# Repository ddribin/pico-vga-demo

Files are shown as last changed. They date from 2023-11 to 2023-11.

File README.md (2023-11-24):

This repository contains the KiCad projects for the "VGA, SD card, and  audio demo boards for Raspberry Pi Pico and Raspberry Pi Pico W" from Chapter 3 of ["Hardware design with RP2040"][hw-design].

- `pico_vga_sd_aud`: Pico version
- `picow_vga_sd_aud`: Pico W version

This is based off of Version 2.2 of the document from 14 June, 2023, but contains some minor updates, such as saving with Version 7, the current version of KiCad.

The original KiCad project for the Pico version can be found at: https://datasheets.raspberrypi.com/rp2040/VGA-KiCAD.zip

The original KiCad project for the Pico W version can be found at: https://datasheets.raspberrypi.com/rp2040/VGA-PicoW-KiCAD.zip

The latest version of "Hardware design with RP2040" can be found at: https://datasheets.raspberrypi.com/rp2040/hardware-design-with-rp2040.pdf

[hw-design]: https://datasheets.raspberrypi.com/rp2040/hardware-design-with-rp2040.pdf

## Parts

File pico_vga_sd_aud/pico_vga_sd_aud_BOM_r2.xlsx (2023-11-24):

RPI-PVAS pico_vga_sd_aud BOM Rev2
17/079/2020
Reference designators | Quantity | Manufacturer Part Number (MPN) | Manufacturer | Description | Value
C1, C2 | 2 | GCM188R71C105KA64J | Murata | CAP CER 1UF 16V X7R 0603 | 1u
C9, C11 | 2 | GRM188R71A225KE15D | Murata | CAP CER 2.2UF 10V X7R 0603 | 2.2u
C3, C10, C16, C19 | 4 | GRM188R61A106KE69J | Murata | CAP CER 10UF 10V X5R 0603 | 10u
C4, C5, C6, C7, C8, C12, C13 | 7 | GRM155R71E104KE14J | Murata | CAP CER 0.1UF 25V X7R 0402 | 100n
C14, C15, C21 | 3 | GRM219R60J476ME44D | Murata | CAP CER 47UF 6.3V X5R 0805 | 47u
C17, C18 | 2 | GRM155R71H222KA01D | Murata | CAP CER 2200PF 50V X7R 0402 | 2.2n
D1 | 1 | MBR120VLSFT1G | ON Semiconductor | DIODE SCHOTTKY 20V 1A SOD123FL | MBR120VLSFT1G
J1, J2 | 2 | SJ-3523-SMT-TR | CUI Devices | CONN JACK STEREO 3.5MM SMD R/A | SJ-3523-SMT
J3 | 1 | 104031-0811 | Molex | CONN MICRO SD CARD PUSH-PULL R/A | 104031-0811
J4 | 1 | L77HDE15SD1CH4F | Amphenol ICC (Commercial Products) | CONN DSUB HD RCPT 15POS R/A SLDR | L77HDE15SD1CH4F
J5 | 1 | 10103594-0001LF | Amphenol ICC (FCI) | CONN RCPT USB2.0 MICRO B SMD R/A | 10103594-0001LF
J6 | 1 | TSW-102-23-T-S | Samtec Inc. | CONN HEADER VERT 2POS 2.54MM | TSW-102-23-T-S
J7 | 1 | 67997-208HLF | Amphenol ICC (FCI) | CONN HEADER VERT 8POS 2.54MM | 67997-208HLF
R1, R2 | 2 | RC0402FR-07220RL | Yageo | RES SMD 220 OHM 1% 1/16W 0402 | 220
R3, R4 | 2 | RC0402FR-07100RL | Yageo | RES SMD 100 OHM 1% 1/16W 0402 | 100
R5, R6 | 2 | RC0402FR-07470RP | Yageo | RES SMD 470 OHM 1% 1/16W 0402 | 470
R7, R8 | 2 | RC0402FR-071K8L | Yageo | RES SMD 1.8K OHM 1% 1/16W 0402 | 1.8K
R10, R11 | 2 | RC0402FR-0747RL | Yageo | RES SMD 47 OHM 1% 1/16W 0402 | 47
R20, R21, R22, R27, R32, R37 | 6 | RC0402FR-071KP | Yageo | RES SMD 1K OHM 1% 1/16W 0402 | 1k
R23, R24 | 2 | RC0402FR-0710KP | Yageo | RES SMD 10K OHM 1% 1/16W 0402 | 10k
R26, R31, R36 | 3 | RC0402FR-07499RL | Yageo | RES SMD 499 OHM 1% 1/16W 0402 | 499
R28, R33, R38 | 3 | RC0402FR-072KL | Yageo | RES SMD 2K OHM 1% 1/16W 0402 | 2k
R29, R34, R39 | 3 | RC0402FR-074K02L | Yageo | RES SMD 4.02K OHM 1% 1/16W 0402 | 4.02k
R30, R35, R40 | 3 | RC0402FR-078K06L | Yageo | RES SMD 8.06K OHM 1% 1/16W 0402 | 8.06k
SW1, SW2, SW3, SW4 | 4 | 434133025816 | Würth Elektronik | TACT SWITCH 4.2X3.2MM VERTICAL T | 434133025816
U1 | 1 | TLV70033DDCR | Texas Instruments | IC REG LINEAR 3.3V 200MA SOT23-5 | TLV70033DDCR
U3 | 1 | NC7WZ16P6X | ON Semiconductor | IC BUF NON-INVERT 5.5V SC70-6 | NC7WZ16P6X
U4 | 1 | PCM5101APWR | Texas Instruments | IC DAC 16/24/32BIT 384K 20TSSOP | PCM5101APWR

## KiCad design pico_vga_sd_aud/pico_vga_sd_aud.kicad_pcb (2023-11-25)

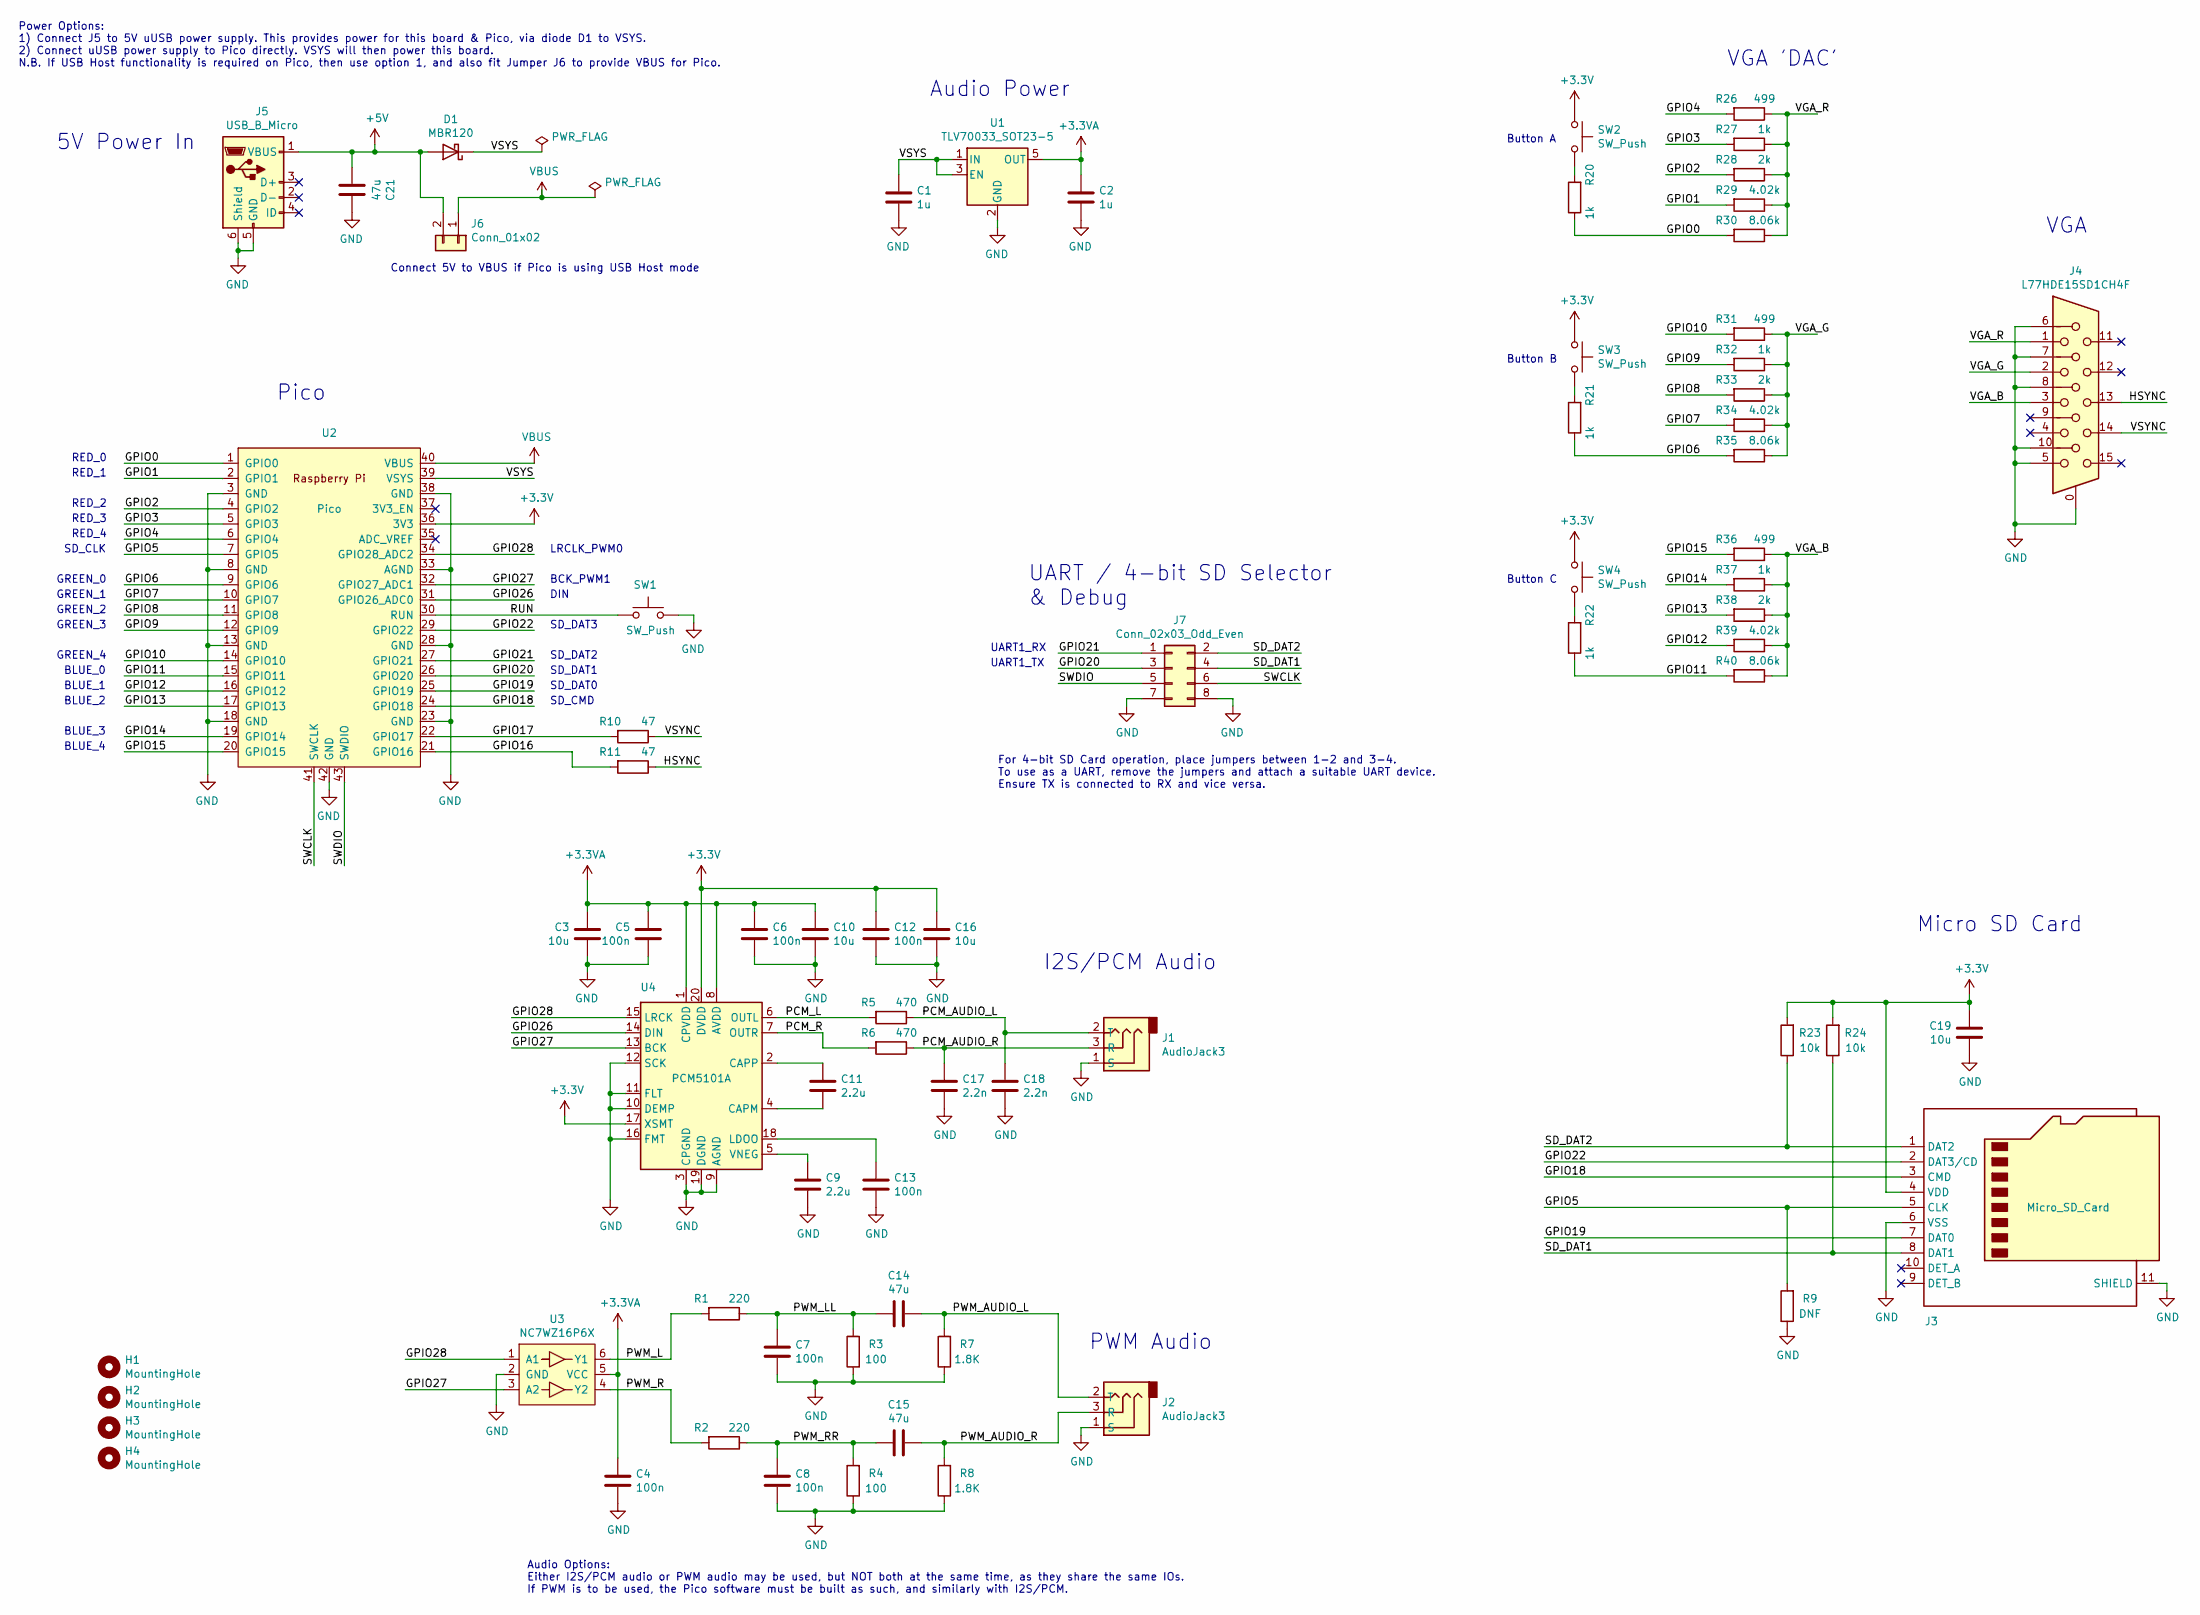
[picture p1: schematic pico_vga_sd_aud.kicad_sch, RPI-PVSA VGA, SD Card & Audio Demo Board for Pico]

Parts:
C1, C2: 1u; C_0603_1608Metric
C3, C10, C16, C19: 10u; C_0603_1608Metric
C4, C5, C6, C7, C8, C12, C13: 100n; C_0402_1005Metric
C9, C11: 2.2u; C_0603_1608Metric
C14, C15, C21: 47u; C_0805_2012Metric
C17, C18: 2.2n; C_0402_1005Metric
D1: MBR120; MBR120_SOD-123
H1, H2, H3, H4: MountingHole; MountingHole_2.7mm_M2.5
J1, J2: AudioJack3; CUI_SJ-3523-audio-jack
J3: Micro_SD_Card; microSD_HC_Molex_104031-0811
J4: L77HDE15SD1CH4F; DSUB-15-L77HDE15SD1CH4F
J5: USB_B_Micro; USB_Micro-B_Amphenol_10103594-0001LF_Horizontal_modified
J6: Conn_01x02; PinHeader_1x02_P2.54mm_Vertical
J7: Conn_02x03_Odd_Even; PinHeader_2x04_P2.54mm_Vertical
R1, R2: 220; R_0402_1005Metric
R3, R4: 100; R_0402_1005Metric
R5, R6: 470; R_0402_1005Metric
R7, R8: 1.8K; R_0402_1005Metric
R9: DNF; R_0402_1005Metric
R10, R11: 47; R_0402_1005Metric
R20, R21, R22, R27, R32, R37: 1k; R_0402_1005Metric
R23, R24: 10k; R_0402_1005Metric
R26, R31, R36: 499; R_0402_1005Metric
R28, R33, R38: 2k; R_0402_1005Metric
R29, R34, R39: 4.02k; R_0402_1005Metric
R30, R35, R40: 8.06k; R_0402_1005Metric
SW1, SW2, SW3, SW4: SW_Push; SW_Push_1P1T_NO_Vertical_Wuerth_434133025816
U1: TLV70033_SOT23-5; SOT-23-5
U2: Pico; RPi_Pico_SMD
U3: NC7WZ16P6X; SOT-363_SC-70-6
U4: PCM5101A; TSSOP-20_4.4x6.5mm_P0.65mm

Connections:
+3.3V: C12.1, C16.1, C19.1, J3.4 (VDD), R23.2, R24.2, SW2.1, SW3.1, SW4.1, U2.36 (3V3), U4.17 (XSMT), U4.20 (DVDD)
+3.3VA: C2.1, C3.1, C4.1, C5.1, C6.1, C10.1, U1.5 (OUT), U3.5 (VCC), U4.1 (CPVDD), U4.8 (AVDD)
+5V: C21.2, D1.2 (A), J5.1 (VBUS), J6.2
/GPIO0: R20.1, R30.2, U2.1 (GPIO0)
/GPIO1: R29.2, U2.2 (GPIO1)
/GPIO2: R28.2, U2.4 (GPIO2)
/GPIO3: R27.2, U2.5 (GPIO3)
/GPIO4: R26.2, U2.6 (GPIO4)
/GPIO5: J3.5 (CLK), R9.2, U2.7 (GPIO5)
/GPIO6: R21.1, R35.2, U2.9 (GPIO6)
/GPIO7: R34.2, U2.10 (GPIO7)
/GPIO8: R33.2, U2.11 (GPIO8)
/GPIO9: R32.2, U2.12 (GPIO9)
/GPIO10: R31.2, U2.14 (GPIO10)
/GPIO11: R22.1, R40.2, U2.15 (GPIO11)
/GPIO12: R39.2, U2.16 (GPIO12)
/GPIO13: R38.2, U2.17 (GPIO13)
/GPIO14: R37.2, U2.19 (GPIO14)
/GPIO15: R36.2, U2.20 (GPIO15)
/GPIO16: R11.2, U2.21 (GPIO16)
/GPIO17: R10.2, U2.22 (GPIO17)
/GPIO18: J3.3 (CMD), U2.24 (GPIO18)
/GPIO19: J3.7 (DAT0), U2.25 (GPIO19)
/GPIO20: J7.3, U2.26 (GPIO20)
/GPIO21: J7.1, U2.27 (GPIO21)
/GPIO22: J3.2 (DAT3/CD), U2.29 (GPIO22)
/GPIO26: U2.31 (GPIO26_ADC0), U4.14 (DIN)
/GPIO27: U2.32 (GPIO27_ADC1), U3.3 (A2), U4.13 (BCK)
/GPIO28: U2.34 (GPIO28_ADC2), U3.1 (A1), U4.15 (LRCK)
/HSYNC: J4.13, R11.1
/PCM_AUDIO_L: C18.1, J1.2 (T), R5.1
/PCM_AUDIO_R: C17.1, J1.3 (R), R6.1
/PCM_L: R5.2, U4.6 (OUTL)
/PCM_R: R6.2, U4.7 (OUTR)
/PWM_AUDIO_L: C14.1, J2.2 (T), R7.2
/PWM_AUDIO_R: C15.1, J2.3 (R), R8.2
/PWM_L: R1.2, U3.6 (Y1)
/PWM_LL: C7.1, C14.2, R1.1, R3.2
/PWM_R: R2.2, U3.4 (Y2)
/PWM_RR: C8.1, C15.2, R2.1, R4.2
/RUN: SW1.1, U2.30 (RUN)
/SD_DAT1: J3.8 (DAT1), J7.4, R24.1
/SD_DAT2: J3.1 (DAT2), J7.2, R23.1
/SWCLK: J7.6, U2.41 (SWCLK)
/SWDIO: J7.5, U2.43 (SWDIO)
/VGA_B: J4.3, R36.1, R37.1, R38.1, R39.1, R40.1
/VGA_G: J4.2, R31.1, R32.1, R33.1, R34.1, R35.1
/VGA_R: J4.1, R26.1, R27.1, R28.1, R29.1, R30.1
/VSYNC: J4.14, R10.1
/VSYS: C1.1, D1.1 (K), U1.1 (IN), U1.3 (EN), U2.39 (VSYS)
GND: C1.2, C2.2, C3.2, C4.2, C5.2, C6.2, C7.2, C8.2, C9.2, C10.2, C12.2, C13.2, C16.2, C17.2, C18.2, C19.2, C21.1, J1.1 (S), J2.1 (S), J3.6 (VSS), J3.11 (SHIELD), J4.0, J4.5, J4.6, J4.7, J4.8, J4.10, J5.5 (GND), J5.6 (Shield), J7.7, J7.8, R3.1, R4.1, R7.1, R8.1, R9.1, SW1.2, U1.2 (GND), U2.3 (GND), U2.8 (GND), U2.13 (GND), U2.18 (GND), U2.23 (GND), U2.28 (GND), U2.33 (AGND), U2.38 (GND), U2.42 (GND), U3.2 (GND), U4.3 (CPGND), U4.9 (AGND), U4.10 (DEMP), U4.11 (FLT), U4.12 (SCK), U4.16 (FMT), U4.19 (DGND)
unnamed: R20.2, SW2.2
unnamed: R21.2, SW3.2
unnamed: R22.2, SW4.2
unnamed: C11.2, U4.4 (CAPM)
unnamed: C11.1, U4.2 (CAPP)
unnamed: C13.1, U4.18 (LDOO)
unnamed: C9.1, U4.5 (VNEG)
VBUS: J6.1, U2.40 (VBUS)

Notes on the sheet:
RED_4
RED_0
GREEN_0
SD_CLK
PWM Audio
SD_CMD
SD_DAT3
RED_3
UART1_RX
LRCLK_PWM0
DIN
BLUE_1
VGA
BCK_PWM1
SD_DAT1
GREEN_3
GREEN_2
UART / 4-bit SD Selector & Debug
RED_2
GREEN_4
Audio Options: Either I2S/PCM audio or PWM audio may be used, but NOT both at the same time, as they share the same IOs. If PWM is to be used, the Pico software must be built as such, and similarly with I2S/PCM.
I2S/PCM Audio
Audio Power
Button C
5V Power In
VGA 'DAC'
Button A
SD_DAT0
Power Options: 1) Connect J5 to 5V uUSB power supply. This provides power for this board & Pico, via diode D1 to VSYS. 2) Connect uUSB power supply to Pico directly. VSYS will then power this board. N.B. If USB Host functionality is required on Pico, then use option 1, and also fit Jumper J6 to pro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
Connect 5V to VBUS if Pico is using USB Host mode
Button B
Pico
For 4-bit SD Card operation, place jumpers between 1-2 and 3-4. To use as a UART, remove the jumpers and attach a suitable UART device. Ensure TX is connected to RX and vice versa.
BLUE_4
RED_1
BLUE_3
BLUE_0
UART1_TX
Micro SD Card
GREEN_1

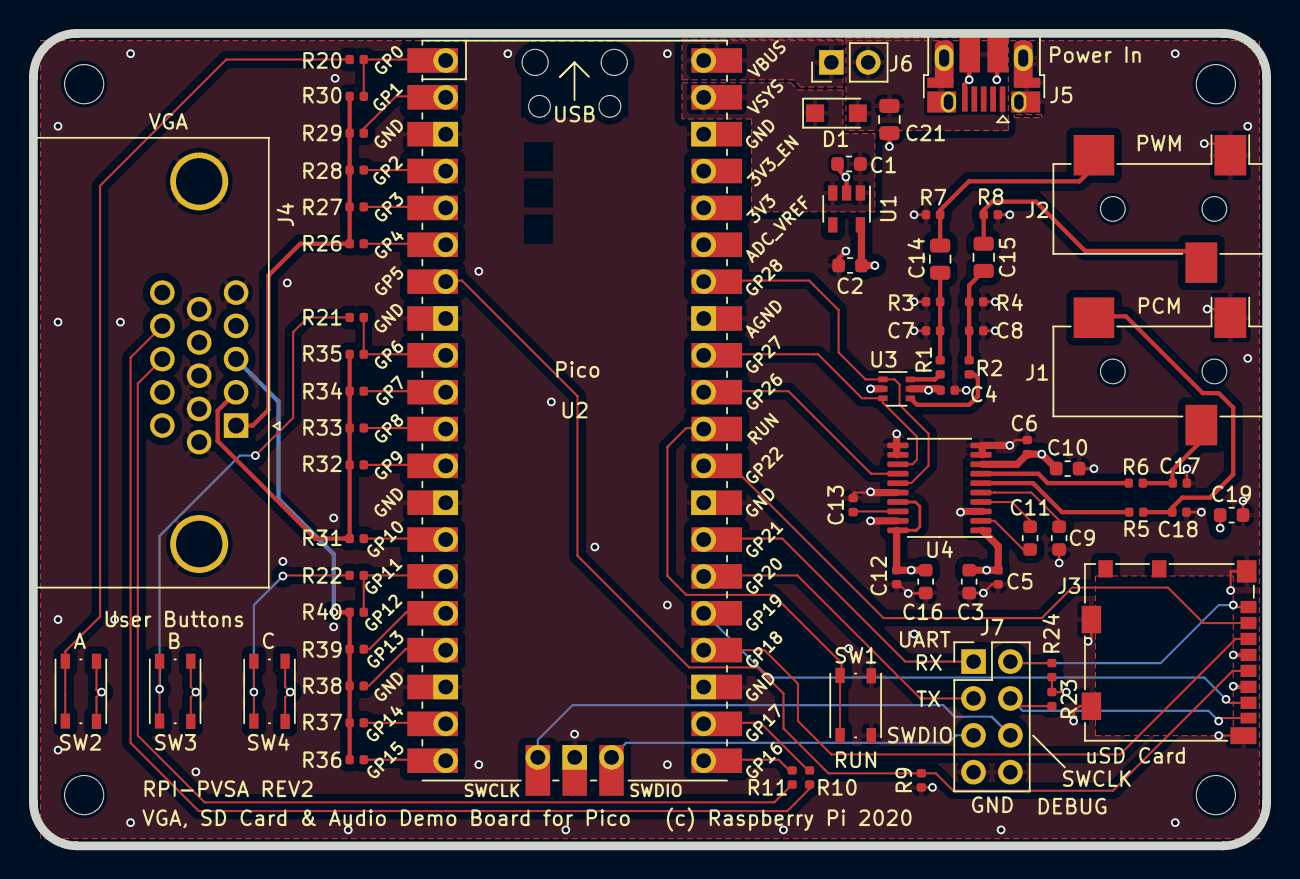
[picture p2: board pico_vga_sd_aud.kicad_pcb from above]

Board: 4 copper layers, 85.0 x 56.0 mm, 71 parts (0 on the bottom side), 59 nets.

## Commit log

2023-11-24 Initial import of KiCad files
    [pico_vga_sd_aud.kicad_pcb, pico_vga_sd_aud.sch, pico_vga_sd_aud_BOM_r2.xlsx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]
2023-11-24 picow: Save files in KiCad 7.0.9 to upgrade them
    [picow_vga_sd_aud.kicad_pcb, picow_vga_sd_aud.kicad_sch]
2023-11-24 Start moving Pico symbols and footprints to their own library
2023-11-24 picow: Upgrade project to Verison 7.0.9
    Fix missing symbols. Remove old project files.
    [pico_vga_sd_aud.kicad_pcb, pico_vga_sd_aud.kicad_sch, pico_vga_sd_aud.sch]
2023-11-24 pico: Update footprint to new one with a keepout
    Update symbol to new one
    [pico_vga_sd_aud.kicad_pcb, pico_vga_sd_aud.kicad_sch]
2023-11-24 picow: Update new footprint (with keepout) and symbol
    [picow_vga_sd_aud.kicad_pcb, picow_vga_sd_aud.kicad_sch]
2023-11-25 picow: Get ERC to pass
    [picow_vga_sd_aud.kicad_pcb, picow_vga_sd_aud.kicad_sch]
2023-11-25 pico: Get ERC to pass
    [pico_vga_sd_aud.kicad_sch]
2023-11-25 Fix up keepout areas to allow pads under USB
    [pico_vga_sd_aud.kicad_pcb]

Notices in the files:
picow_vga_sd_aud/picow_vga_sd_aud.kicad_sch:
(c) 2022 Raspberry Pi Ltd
